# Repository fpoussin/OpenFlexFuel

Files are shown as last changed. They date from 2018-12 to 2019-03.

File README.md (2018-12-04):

View this project on [CADLAB.io](https://cadlab.io/project/1489). 

# OpenFlexFuel

This is a small project I started to convert my Honda Accord (CH7) to E85.  
The plan is to integrate a small pcb module into the ECU instead of piggybacking wires under the hood.  

There will be a small I2C oled module to monitor duty cycle, fuel ethanol content and possible water contamination.

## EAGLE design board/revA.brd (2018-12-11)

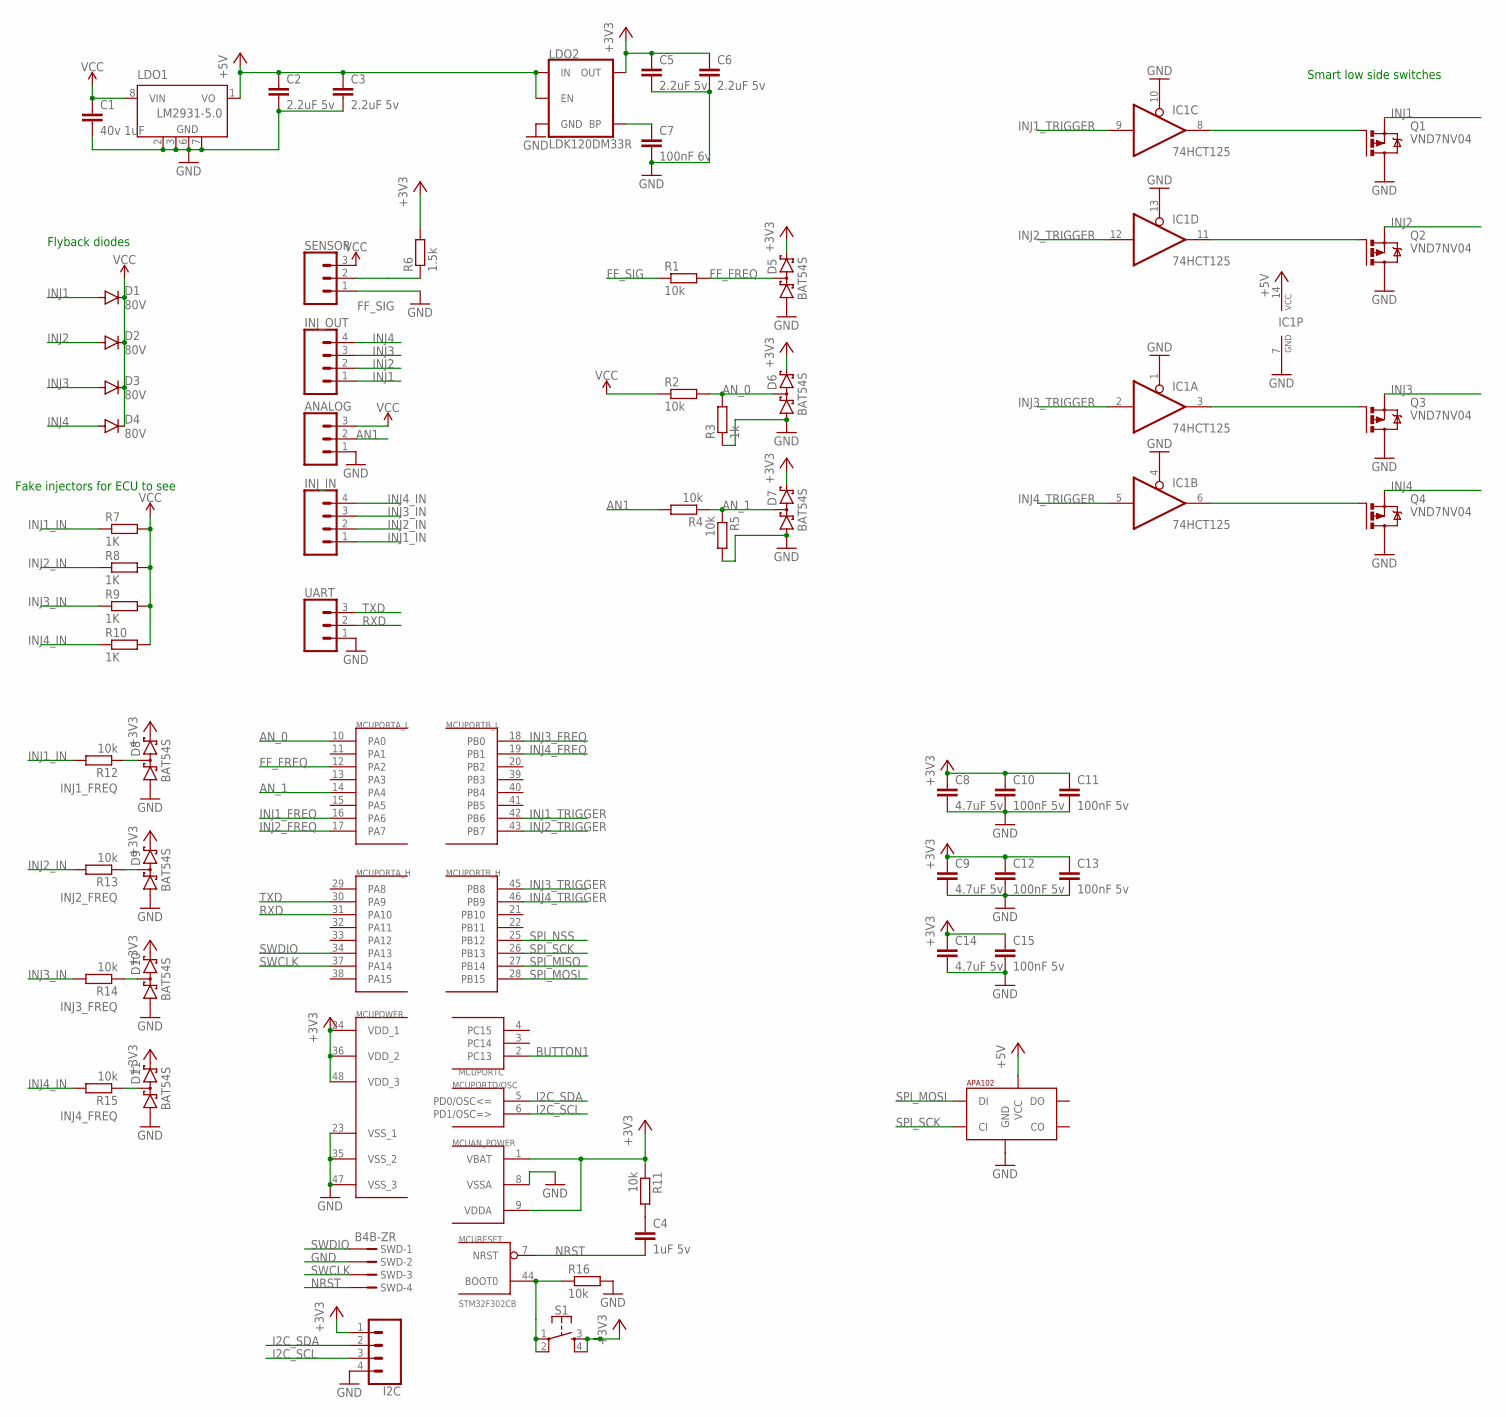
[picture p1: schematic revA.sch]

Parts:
ANALOG: CONN_03POLAR_LOCK; MOLEX-1X3_LOCK
C1: 40v 1uF; C0603
C2, C3, C5, C6: 2.2uF 5v; C0603
C4: 1uF 5v; C0603
C7: 100nF 6v; C0603
C8, C9, C14: 4.7uF 5v; C0603
C10, C11, C12, C13, C15: 100nF 5v; C0603
D1, D2, D3, D4: 80V; SMB
D5, D6, D7, D8, D9, D10, D11: BAT54S; SOT23
I2C: CONN_04POLAR_LOCK; MOLEX-1X4_LOCK
IC1: 74HCT125; TSSOP14
INJ_IN: CONN_04POLAR_LOCK; MOLEX-1X4_LOCK
INJ_OUT: CONN_04POLAR_LOCK; MOLEX-1X4_LOCK
LDO1: LM2931-5.0; SO08
LDO2: LDK120DM33R; SOT23-5
LED: APA1025050; APA102_5050
MCU: STM32F302CB; LQFP48_2
Q1, Q2, Q3, Q4: VND7NV04; D-PAK_TO252AA
R1, R2, R4, R5, R11, R12, R13, R14, R15, R16: 10k; R0603
R3: 1k; R0603
R6: 1.5k; R0603
R7, R8, R9, R10: 1K; 0414/15
S1: MOMENTARY-SWITCH-SPST-2-SMD-5.2MM; TACTILE_SWITCH_SMD_5.2MM
SENSOR: CONN_03POLAR_LOCK; MOLEX-1X3_LOCK
SWD: B4B-ZR
UART: CONN_03POLAR_LOCK; MOLEX-1X3_LOCK

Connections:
+3V3: C5.1, C6.1, C8.1, C9.1, C10.1, C11.1, C12.1, C13.1, C14.1, C15.1, D5.2 (C2), D6.2 (C2), D7.2 (C2), D8.2 (C2), D9.2 (C2), D10.2 (C2), D11.2 (C2), I2C.1, LDO2.5 (OUT), MCU.1 (VBAT), MCU.9 (VDDA), MCU.24 (VDD_1), MCU.36 (VDD_2), MCU.48 (VDD_3), R6.2, R11.1, S1.3, S1.4
+5V: C2.1, C3.1, IC1.14 (VCC), LDO1.1 (VO), LDO2.1 (IN), LDO2.3 (EN), LED.1 (VCC)
AN1: ANALOG.2, R4.2
AN_0: D6.3 (C1A2), MCU.10 (PA0), R2.2, R3.2
AN_1: D7.3 (C1A2), MCU.14 (PA4), R4.1, R5.1
BUTTON: MCU.44 (BOOT0), R16.1, S1.1, S1.2
BUTTON1: MCU.2 (PC13)
FF_FREQ: D5.3 (C1A2), MCU.12 (PA2), R1.2
FF_SIG: R1.1, R6.1, SENSOR.2
GND: ANALOG.1, C1.2, C2.2, C3.2, C5.2, C6.2, C7.2, C8.2, C9.2, C10.2, C11.2, C12.2, C13.2, C14.2, C15.2, D5.1 (A1), D6.1 (A1), D7.1 (A1), D8.1 (A1), D9.1 (A1), D10.1 (A1), D11.1 (A1), I2C.4, IC1.1 (OE), IC1.4 (OE), IC1.7 (GND), IC1.10 (OE), IC1.13 (OE), LDO1.2 (GND), LDO1.3 (GND), LDO1.6 (GND), LDO1.7 (GND), LDO2.2 (GND), LED.6 (GND), MCU.8 (VSSA), MCU.23 (VSS_1), MCU.35 (VSS_2), MCU.47 (VSS_3), Q1.4 (D), Q2.4 (D), Q3.4 (D), Q4.4 (D), R3.1, R5.2, R16.2, SENSOR.1, SWD.2, UART.1
I2C_SCL: I2C.3, MCU.6 (PD1/OSC=>)
I2C_SDA: I2C.2, MCU.5 (PD0/OSC<=)
INJ1: D1.A, INJ_OUT.1, Q1.3 (S)
INJ1_FREQ: D8.3 (C1A2), MCU.16 (PA6), R12.1
INJ1_IN: INJ_IN.1, R7.1, R12.2
INJ1_TRIGGER: IC1.9 (I), MCU.42 (PB6)
INJ2: D2.A, INJ_OUT.2, Q2.3 (S)
INJ2_FREQ: D9.3 (C1A2), MCU.17 (PA7), R13.1
INJ2_IN: INJ_IN.2, R8.1, R13.2
INJ2_TRIGGER: IC1.12 (I), MCU.43 (PB7)
INJ3: D3.A, INJ_OUT.3, Q3.3 (S)
INJ3_FREQ: D10.3 (C1A2), MCU.18 (PB0), R14.1
INJ3_IN: INJ_IN.3, R9.1, R14.2
INJ3_TRIGGER: IC1.2 (I), MCU.45 (PB8)
INJ4: D4.A, INJ_OUT.4, Q4.3 (S)
INJ4_FREQ: D11.3 (C1A2), MCU.19 (PB1), R15.1
INJ4_IN: INJ_IN.4, R10.1, R15.2
INJ4_TRIGGER: IC1.5 (I), MCU.46 (PB9)
unnamed: C4.1, R11.2
unnamed: C7.1, LDO2.4 (BP)
unnamed: IC1.11 (O), Q2.1 (G)
unnamed: IC1.8 (O), Q1.1 (G)
unnamed: IC1.6 (O), Q4.1 (G)
unnamed: IC1.3 (O), Q3.1 (G)
NRST: C4.2, MCU.7 (NRST), SWD.4
RXD: MCU.31 (PA10), UART.2
SPI_MISO: MCU.27 (PB14)
SPI_MOSI: LED.4 (DI), MCU.28 (PB15)
SPI_NSS: MCU.25 (PB12)
SPI_SCK: LED.5 (CI), MCU.26 (PB13)
SWCLK: MCU.37 (PA14), SWD.3
SWDIO: MCU.34 (PA13), SWD.1
TXD: MCU.30 (PA9), UART.3
VCC: ANALOG.3, C1.1, D1.C, D2.C, D3.C, D4.C, LDO1.8 (VIN), R2.1, R7.2, R8.2, R9.2, R10.2, SENSOR.3

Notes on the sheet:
Flyback diodes
Fake injectors for ECU to see
Smart low side switches

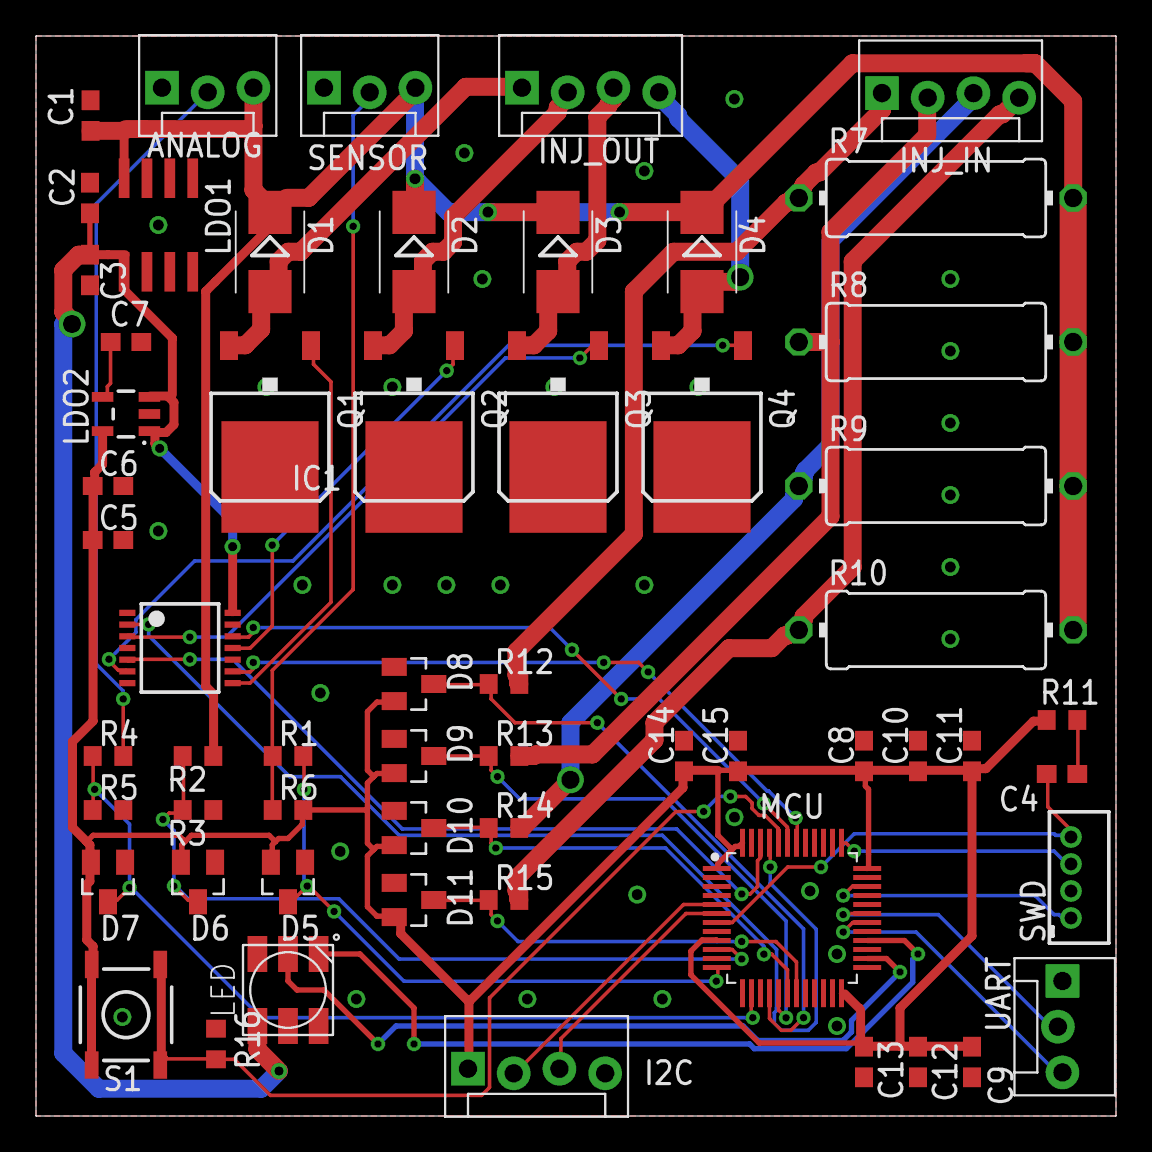
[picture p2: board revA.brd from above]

Board: 2 copper layers, 60.0 x 60.0 mm, 59 parts (0 on the bottom side), 41 nets.

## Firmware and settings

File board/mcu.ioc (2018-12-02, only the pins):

Mcu.UserName=STM32F302CBTx
PA0.GPIO_Label=AN0
PA0.Signal=ADC1_IN1
PA10.Signal=USART1_RX
PA13.Signal=SYS_JTMS-SWDIO
PA14.Signal=SYS_JTCK-SWCLK
PA2.GPIO_Label=FF_FREQ
PA2.Signal=S_TIM15_CH1
PA4.GPIO_Label=DAC1
PA4.Signal=COMP_DAC1_group
PA5.GPIO_Label=AN1
PA5.Signal=ADC2_IN2
PA6.GPIO_Label=INJ1_IN
PA6.Signal=S_TIM3_CH1
PA7.GPIO_Label=INJ2_IN
PA7.Signal=S_TIM3_CH2
PA9.Signal=USART1_TX
PB0.GPIO_Label=INJ3_IN
PB0.Signal=S_TIM3_CH3
PB1.GPIO_Label=INJ4_IN
PB1.Signal=S_TIM3_CH4
PB6.GPIO_Label=INJ1_OUT
PB6.Signal=S_TIM4_CH1
PB7.GPIO_Label=INJ2_OUT
PB7.Signal=S_TIM4_CH2
PB8.GPIO_Label=INJ3_OUT
PB8.Signal=S_TIM4_CH3
PB9.GPIO_Label=INJ4_OUT
PB9.Signal=S_TIM4_CH4
PC13.GPIO_Label=BUTTON1
PC13.Signal=GPIO_Input
PF0-OSC_IN.Signal=I2C2_SDA
PF1-OSC_OUT.Signal=I2C2_SCL

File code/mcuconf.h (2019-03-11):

/*
    ChibiOS - Copyright (C) 2006..2018 Giovanni Di Sirio

    Licensed under the Apache License, Version 2.0 (the "License");
    you may not use this file except in compliance with the License.
    You may obtain a copy of the License at

        http://www.apache.org/licenses/LICENSE-2.0

    Unless required by applicable law or agreed to in writing, software
    distributed under the License is distributed on an "AS IS" BASIS,
    WITHOUT WARRANTIES OR CONDITIONS OF ANY KIND, either express or implied.
    See the License for the specific language governing permissions and
    limitations under the License.
*/

#ifndef MCUCONF_H
#define MCUCONF_H

/*
 * STM32F3xx drivers configuration.
 * The following settings override the default settings present in
 * the various device driver implementation headers.
 * Note that the settings for each driver only have effect if the whole
 * driver is enabled in halconf.h.
 *
 * IRQ priorities:
 * 15...0       Lowest...Highest.
 *
 * DMA priorities:
 * 0...3        Lowest...Highest.
 */

#define STM32F3xx_MCUCONF
#define STM32F303_MCUCONF

/*
 * HAL driver system settings.
 */
#define STM32_NO_INIT                       FALSE
#define STM32_PVD_ENABLE                    FALSE
#define STM32_PLS                           STM32_PLS_LEV0
#define STM32_HSI_ENABLED                   TRUE
#define STM32_LSI_ENABLED                   TRUE
#define STM32_HSE_ENABLED                   TRUE
#define STM32_LSE_ENABLED                   FALSE
#define STM32_SW                            STM32_SW_PLL
#define STM32_PLLSRC                        STM32_PLLSRC_HSE
#define STM32_PREDIV_VALUE                  1
#define STM32_PLLMUL_VALUE                  9
#define STM32_HPRE                          STM32_HPRE_DIV1
#define STM32_PPRE1                         STM32_PPRE1_DIV2
#define STM32_PPRE2                         STM32_PPRE2_DIV2
#define STM32_MCOSEL                        STM32_MCOSEL_NOCLOCK
#define STM32_ADC12PRES                     STM32_ADC12PRES_DIV1
#define STM32_ADC34PRES                     STM32_ADC34PRES_DIV1
#define STM32_USART1SW                      STM32_USART1SW_PCLK
#define STM32_USART2SW                      STM32_USART2SW_PCLK
#define STM32_USART3SW                      STM32_USART3SW_PCLK
#define STM32_UART4SW                       STM32_UART4SW_PCLK
#define STM32_UART5SW                       STM32_UART5SW_PCLK
#define STM32_I2C1SW                        STM32_I2C1SW_SYSCLK
#define STM32_I2C2SW                        STM32_I2C2SW_SYSCLK
#define STM32_TIM1SW                        STM32_TIM1SW_PCLK2
#define STM32_TIM8SW                        STM32_TIM8SW_PCLK2
#define STM32_RTCSEL                        STM32_RTCSEL_LSI
#define STM32_USB_CLOCK_REQUIRED            TRUE
#define STM32_USBPRE                        STM32_USBPRE_DIV1P5

/*
 * IRQ system settings.
 */
#define STM32_IRQ_EXTI0_PRIORITY            6
#define STM32_IRQ_EXTI1_PRIORITY            6
#define STM32_IRQ_EXTI2_PRIORITY            6
#define STM32_IRQ_EXTI3_PRIORITY            6
#define STM32_IRQ_EXTI4_PRIORITY            6
#define STM32_IRQ_EXTI5_9_PRIORITY          6
#define STM32_IRQ_EXTI10_15_PRIORITY        6
#define STM32_IRQ_EXTI16_PRIORITY           6
#define STM32_IRQ_EXTI17_PRIORITY           6
#define STM32_IRQ_EXTI18_PRIORITY           6
#define STM32_IRQ_EXTI19_PRIORITY           6
#define STM32_IRQ_EXTI20_PRIORITY           6
#define STM32_IRQ_EXTI21_22_29_PRIORITY     6
#define STM32_IRQ_EXTI30_32_PRIORITY        6
#define STM32_IRQ_EXTI33_PRIORITY           6
#define STM32_IRQ_TIM1_BRK_TIM15_PRIORITY   7
#define STM32_IRQ_TIM1_UP_TIM16_PRIORITY    7
#define STM32_IRQ_TIM1_TRGCO_TIM17_PRIORITY 7
#define STM32_IRQ_TIM1_CC_PRIORITY          7

/*
 * ADC driver system settings.
 */
#define STM32_ADC_DUAL_MODE                 FALSE
#define STM32_ADC_COMPACT_SAMPLES           FALSE
#define STM32_ADC_USE_ADC1                  TRUE
#define STM32_ADC_USE_ADC2                  TRUE
#define STM32_ADC_USE_ADC3                  TRUE
#define STM32_ADC_USE_ADC4                  TRUE
#define STM32_ADC_ADC1_DMA_STREAM           STM32_DMA_STREAM_ID(1, 1)
#define STM32_ADC_ADC2_DMA_STREAM           STM32_DMA_STREAM_ID(2, 1)
#define STM32_ADC_ADC3_DMA_STREAM           STM32_DMA_STREAM_ID(2, 5)
#define STM32_ADC_ADC4_DMA_STREAM           STM32_DMA_STREAM_ID(2, 2)
#define STM32_ADC_ADC1_DMA_PRIORITY         2
#define STM32_ADC_ADC2_DMA_PRIORITY         2
#define STM32_ADC_ADC3_DMA_PRIORITY         2
#define STM32_ADC_ADC4_DMA_PRIORITY         2
#define STM32_ADC_ADC12_IRQ_PRIORITY        5
#define STM32_ADC_ADC3_IRQ_PRIORITY         5
#define STM32_ADC_ADC4_IRQ_PRIORITY         5
#define STM32_ADC_ADC1_DMA_IRQ_PRIORITY     5
#define STM32_ADC_ADC2_DMA_IRQ_PRIORITY     5
#define STM32_ADC_ADC3_DMA_IRQ_PRIORITY     5
#define STM32_ADC_ADC4_DMA_IRQ_PRIORITY     5
#define STM32_ADC_ADC12_CLOCK_MODE          ADC_CCR_CKMODE_AHB_DIV1
#define STM32_ADC_ADC34_CLOCK_MODE          ADC_CCR_CKMODE_AHB_DIV1

/*
 * CAN driver system settings.
 */
#define STM32_CAN_USE_CAN1                  FALSE
#define STM32_CAN_CAN1_IRQ_PRIORITY         11

/*
 * DAC driver system settings.
 */
#define STM32_DAC_DUAL_MODE                 FALSE
#define STM32_DAC_USE_DAC1_CH1              TRUE
#define STM32_DAC_USE_DAC1_CH2              TRUE
#define STM32_DAC_DAC1_CH1_IRQ_PRIORITY     10
#define STM32_DAC_DAC1_CH2_IRQ_PRIORITY     10
#define STM32_DAC_DAC1_CH1_DMA_PRIORITY     2
#define STM32_DAC_DAC1_CH2_DMA_PRIORITY     2

/*
 * GPT driver system settings.
 */
#define STM32_GPT_USE_TIM1                  FALSE
#define STM32_GPT_USE_TIM2                  FALSE
#define STM32_GPT_USE_TIM3                  FALSE
#define STM32_GPT_USE_TIM4                  FALSE
#define STM32_GPT_USE_TIM6                  FALSE
#define STM32_GPT_USE_TIM7                  FALSE
#define STM32_GPT_USE_TIM8                  FALSE
#define STM32_GPT_USE_TIM15                 FALSE
#define STM32_GPT_USE_TIM16                 FALSE
#define STM32_GPT_USE_TIM17                 FALSE
#define STM32_GPT_TIM1_IRQ_PRIORITY         7
#define STM32_GPT_TIM2_IRQ_PRIORITY         7
#define STM32_GPT_TIM3_IRQ_PRIORITY         7
#define STM32_GPT_TIM4_IRQ_PRIORITY         7
#define STM32_GPT_TIM6_IRQ_PRIORITY         7
#define STM32_GPT_TIM7_IRQ_PRIORITY         7
#define STM32_GPT_TIM8_IRQ_PRIORITY         7

/*
 * I2C driver system settings.
 */
#define STM32_I2C_USE_I2C1                  FALSE
#define STM32_I2C_USE_I2C2                  FALSE
#define STM32_I2C_BUSY_TIMEOUT              50
#define STM32_I2C_I2C1_IRQ_PRIORITY         10
#define STM32_I2C_I2C2_IRQ_PRIORITY         10
#define STM32_I2C_USE_DMA                   TRUE
#define STM32_I2C_I2C1_DMA_PRIORITY         1
#define STM32_I2C_I2C2_DMA_PRIORITY         1
#define STM32_I2C_DMA_ERROR_HOOK(i2cp)      osalSysHalt("DMA failure")
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

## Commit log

2018-11-28 Updating values
    [revA.brd, revA.sch]
2018-11-29 Some routing, adding mosfets
    [revA.brd, revA.sch]
2018-11-29 Adding buffer for mosfets
    [revA.brd, revA.sch]
2018-11-29 Changing buffer package to TSSOP
    [revA.brd, revA.sch]
2018-11-30 Adding wires, protections, switch
    [revA.brd, revA.sch]
2018-12-02 More routing, adding interfaces
    [revA.brd, revA.sch]
2018-12-03 Testing autorouter
    [revA.brd, revA.sch]
2018-12-04 More routing tests
    [revA.brd, revA.sch]
2018-12-05 Cleaning routing a bit
    [revA.brd]
2018-12-09 Cleaning routing
    [revA.brd, revA.sch]
2018-12-11 Adding LED
    [revA.brd, revA.sch]

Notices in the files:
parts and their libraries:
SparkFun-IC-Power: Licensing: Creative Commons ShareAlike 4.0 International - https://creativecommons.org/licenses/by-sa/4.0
